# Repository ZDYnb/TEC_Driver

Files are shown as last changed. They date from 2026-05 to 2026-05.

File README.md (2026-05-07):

# TEC Control Driver
This repository contains the current design progress for the TEC control system and hardware implementation. The control-flow chart and hardware schematic are included in this project. 

### Control Flow Chart

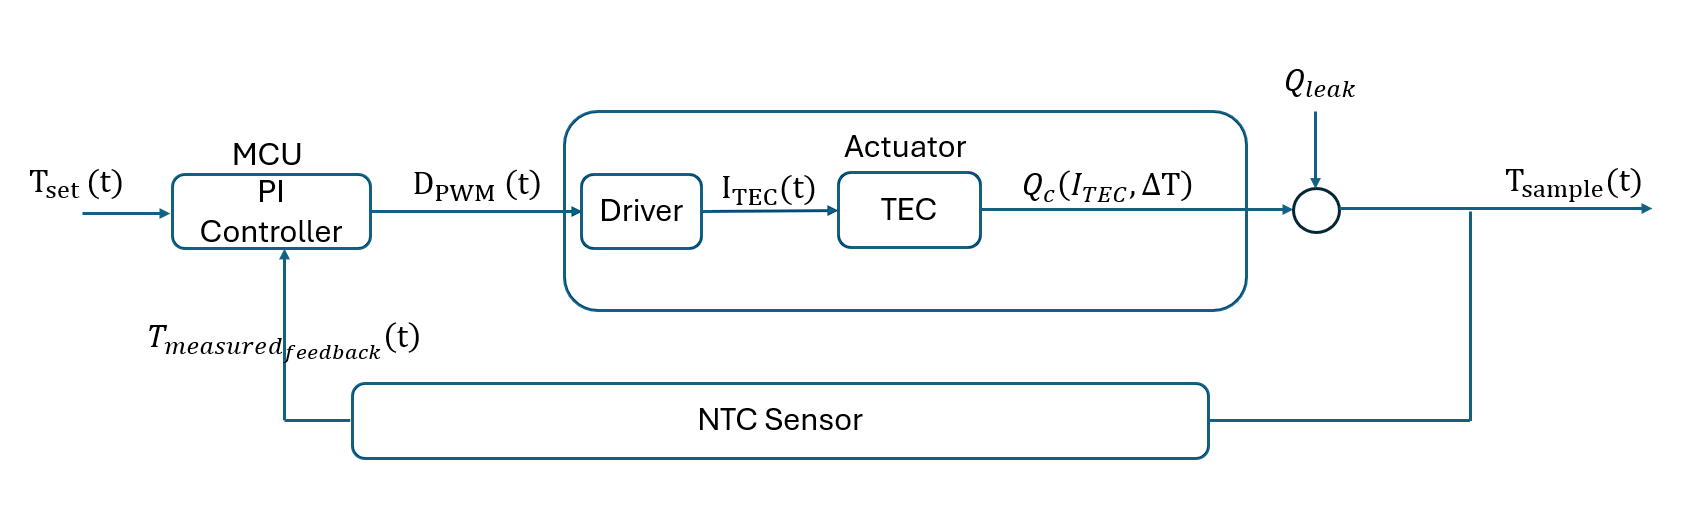
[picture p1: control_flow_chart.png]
Control Flow Chart


### Hardware Schematic

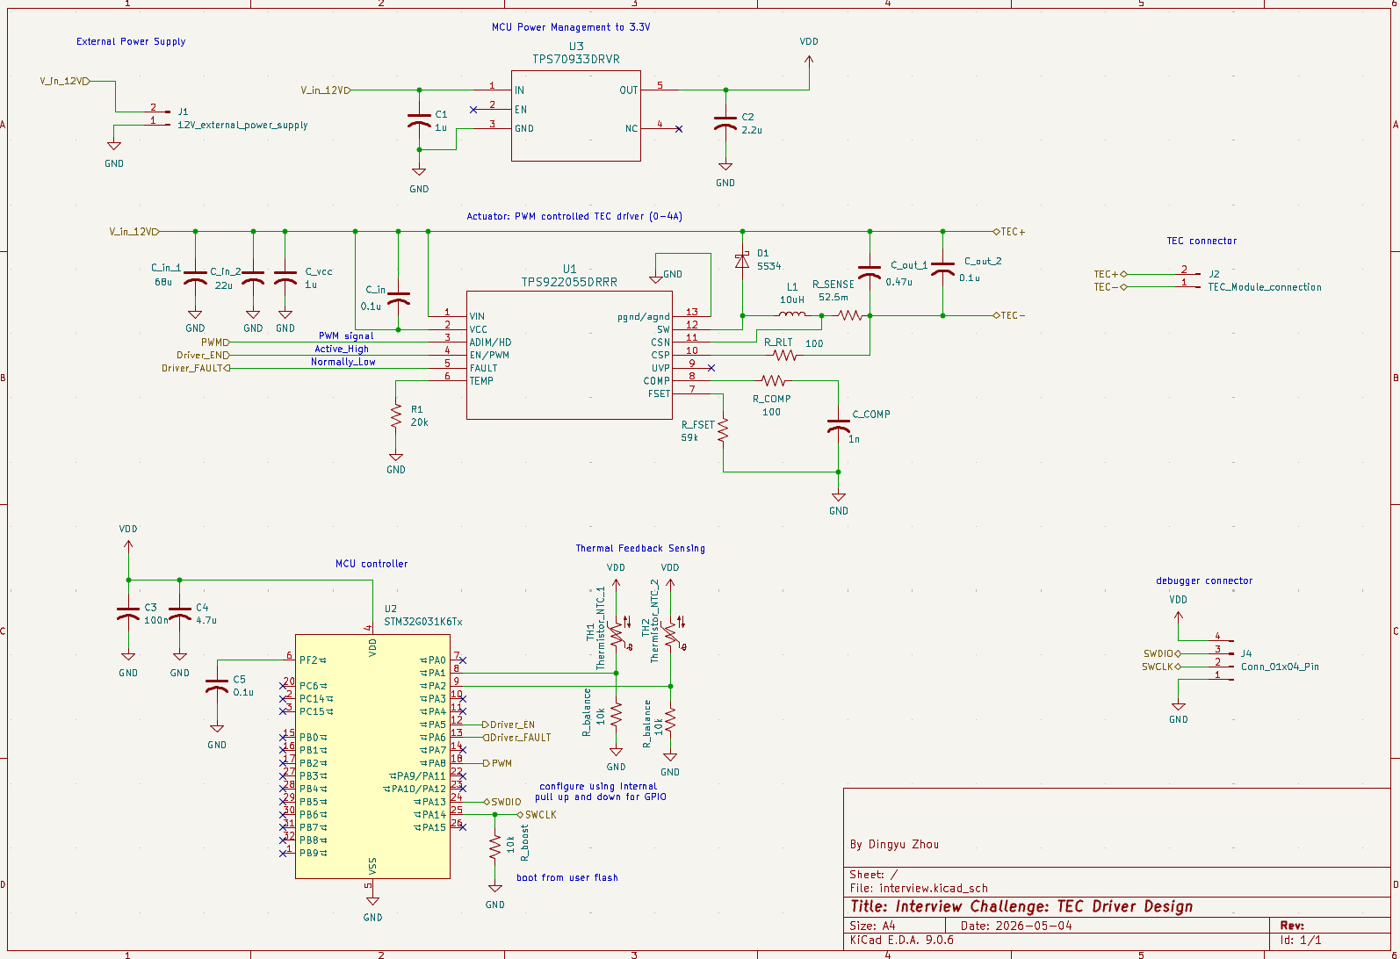
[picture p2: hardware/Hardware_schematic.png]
Hardware Schematic


The full engineering log that contains discussion of circuit design and analysis is also provided as `engineering_log.pdf` in the repository.
## Folder Structure

Contain two folders:

- hardware: contains the KiCad schematic files for the TEC driver circuit design.
- analysis: contains the control-system analysis and simulation files, including the Jupyter    Notebook used for s-domain derivation, PI controller analysis, and time-domain simulation.

## Python Environment Setup

For creating a Python virtual environment and installing the required libraries so the Jupyter Notebook simulation can be run.

Open PowerShell in the project folder and run:

```powershell
python -m venv .venv
.\.venv\Scripts\Activate.ps1
python -m pip install -r requirements.txt
```
Then open the notebook to try yourself in live

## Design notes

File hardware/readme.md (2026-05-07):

# Hardware Schematic Description

Hardware Schematic

This folder contains the hardware schematic for the TEC driver design.

The schematic is divided into several functional modules.

## External Power and Connectors

The external power connector provides the 12V input supply for the system. The TEC connector is used to connect the driver output to the TEC device. A debugging connector is included for MCU flashing and debugging.

## MCU Power Management

The MCU power-management module uses the [`TPS7B6933QDBVR`](https://www.digikey.com/en/products/detail/texas-instruments/TPS7B6933QDBVRQ1/5358037) LDO regulator to convert the 12V input supply into a regulated 3.3V supply for the MCU and its supporting circuitry.

## MCU Controller

The [`STM32G031C6T6`](https://www.digikey.com/en/products/detail/stmicroelectronics/STM32G031C6T6/10300268) MCU is used as the main processor of the system. It reads the thermal feedback signals, processes the control algorithm, and generates the PWM control signal for the TEC driver.

## PWM-Controlled TEC Driver

The TEC driver stage uses the [`TPS922055DRRR`](https://www.digikey.com/en/products/detail/texas-instruments/TPS922055DRRR/22106744) driver IC as the actuator of the system. It receives the PWM control signal from the MCU and controls the TEC output current. The designed output current range is approximately 0A to 3.81A.

## Thermal Feedback Sensing

The thermal feedback sensing module uses [`103AT-4-70374`](https://www.digikey.com/en/products/detail/semitec-usa-corp/103AT-4-70374/16578953) pearl-shaped leaded NTC thermistors connected to the MCU ADC inputs. The MCU reads these feedback signals to estimate the sample temperature and environmental temperature, then adjusts the PWM command for closed-loop temperature control.

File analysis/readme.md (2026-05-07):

# Control Analysis and Test

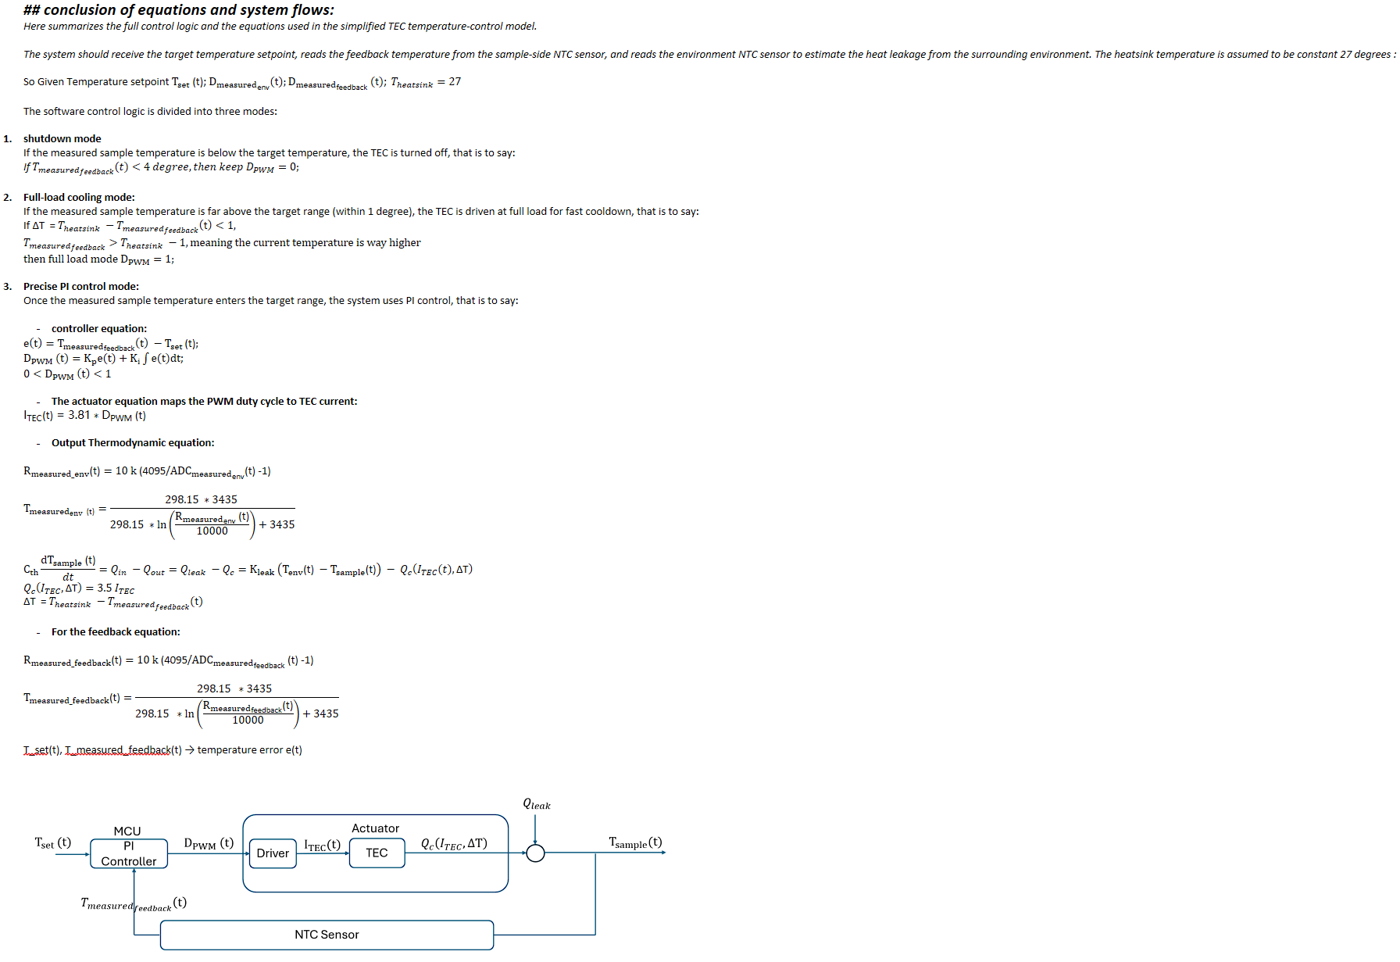
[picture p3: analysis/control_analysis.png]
Control Analysis


All above equations and control flow are analyzed using the Python Jupyter Notebook file included in this folder.

In conclusion, with the help of Python tools, I combined the control equations and derived the transfer function for the TEC control system.

From the s-domain analysis, the closed-loop poles are on the left side of the s-plane, so the control system is stable and can converge to the target temperature.

To get a good tradeoff between response speed and stability, I selected a critically damped response by setting two repeated real poles:

$$
s_1 = s_2 = -\omega_n
$$

This gives a relationship for \(K_p\) and \(K_i\), so they are no longer arbitrary tuning numbers. Instead, they are linked with the system parameters.

So the main parameters are narrowed down to:

$$
C_{th},\ K_{leak},\ \omega_n
$$

Finally, I used time-domain simulation to test the control logic. The simulation shows that the system can converge to the target temperature, and the response curve looks reasonable.
